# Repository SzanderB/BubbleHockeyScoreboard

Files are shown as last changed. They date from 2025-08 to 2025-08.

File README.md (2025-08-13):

# Bubble Hockey Scoreboard

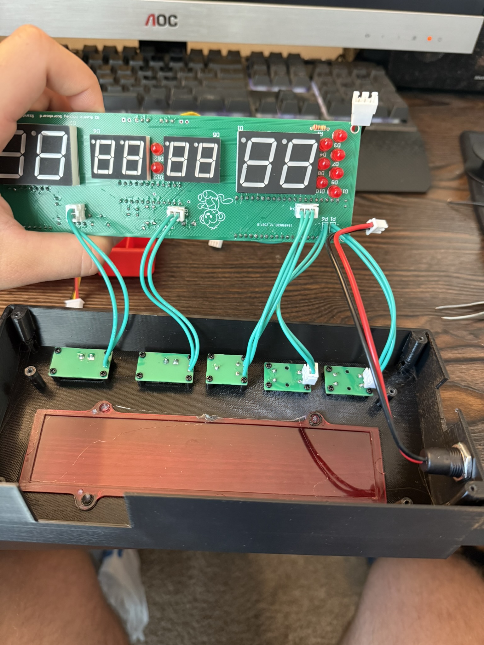
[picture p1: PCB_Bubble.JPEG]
Bubble Hockey Scoreboard
  
[🎥 Video Demo](https://youtu.be/nwzQTY0Y3hk)

## Overview
A fully custom scoreboard for a bubble hockey table (or any goal-based game), built from schematic design to a finished 3D-printed enclosure. Tracks goals automatically, plays audio cues, and supports multiple game modes.  
Includes two versions:
- **V1** – PCB-only prototype for a class project
- **V2** – Redesigned, fully integrated product with mechanical housing

## Features
- Automatic goal detection via beam-break sensors
- Multiple game modes (play to score limit or timed matches)
- Ambient lighting with NeoPixel LEDs
- Audio effects via DFPlayer Mini MP3 player
- Modular design with Molex connectors for easy assembly/disassembly

## Tech Stack / Components
- **MCU:** Raspberry Pi Pico 2
- **Display:** MAX7219-driven 7-segment LEDs
- **Lighting:** NeoPixel LEDs (FastLED library)
- **Audio:** DFPlayer Mini + external amp
- **Enclosure:** Custom 3D-printed case with mounting hardware
- **Other:** Beam-break sensors, tactile buttons, toggle switches, potentiometer

## Design Notes
- Learned to integrate mechanical constraints into PCB design
- Balanced routing efficiency with component placement for enclosure fit
- Iterated enclosure to allow access to key ports while assembled

## Future Improvements
- Better speaker and button hole tolerances in the case
- Integrate light switch state detection directly into firmware
- Correct PCB LED footprint for better fit

## Media
- [Video Demo](https://youtu.be/nwzQTY0Y3hk)

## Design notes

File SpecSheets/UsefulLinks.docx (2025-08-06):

LEDs

https://www.uxcell.com/common-cathode-pin-bit-segment-141-102-039-inch-red-led-display-digital-tube-2pcs-p-1444941.html

https://www.xlitx.com/7-segment-led-dot-matrix/5621ah.html

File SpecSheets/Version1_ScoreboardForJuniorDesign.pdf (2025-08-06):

1

Szander Brenner
4/23/2025
99974691

### EE Design 1 Technical Report Final Project “Bubble Hockey Scoreboard”

## Contents

2

## Introduction

I recently acquired a Bubble Hockey table. It is not a complex and expensive version with a button-deployable puck, but it does come with a scoreboard that tracks goals and game state. However, this scoreboard was broken. The goal of my system was to replace this scoreboard and recover the functionality from the previous version. This meant it needed to have a sensor that can automatically track goals. It needed a speaker that could play sounds with the goals and with the game ending. In addition, it needed some indicator of current goals and game time.
Ideally, this system would be small enough to be mounted to the bubble hockey arena and be powered from a 9V battery. In completion, all these goals were met, but there is room for improvement in the next revision.

## Methods

### Requirements

In this section, I will discuss why I chose the components I did to fulfill the requirements. For this project, we needed an analog input, analog output, digital input, digital output, an analog signal amplified to a speaker, system status displayed on an LCD, and some sort of power regulation.

Since I was designing a scoreboard, I knew that the speaker output would come from a goal score and game ending like in the actual sport. The LCD would display all the game information like game time and score. Furthermore, the sensor most used for detecting if a goal was scored is the beam break sensor. This is the same device used in garage doors to detect if something is blocking the garage door path. This is a digital input as described in its datasheet (Digikey). This takes care of the digital input, analog output and LCD requirements.

The only things left to decide are digital output, and analog input. I originally wanted to have seven segment displays display the number for score and time, but I realized that with that configuration I couldn’t just do GPIO mapping, I would need a special seven segment driver chip to control 8 seven segments. Instead, for simplicity I just used five LEDs for each side to track goals if we are playing a game to either 3 or 5 goals. For the analog input, I decided to use a potentiometer to be a ‘state selector’. You can scroll through the different game options depending on the voltage on the output. Lastly, I went with the switching regulator as my power regulator. While it does take up significantly more space on the PCB, its efficiency was better. This was found in a previous lab. Since I wanted this to be battery powered, I could sacrifice that space for longer lasting batteries. With all my components selected, I can begin researching more into the components and designing the system.

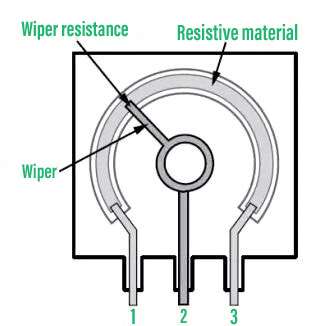
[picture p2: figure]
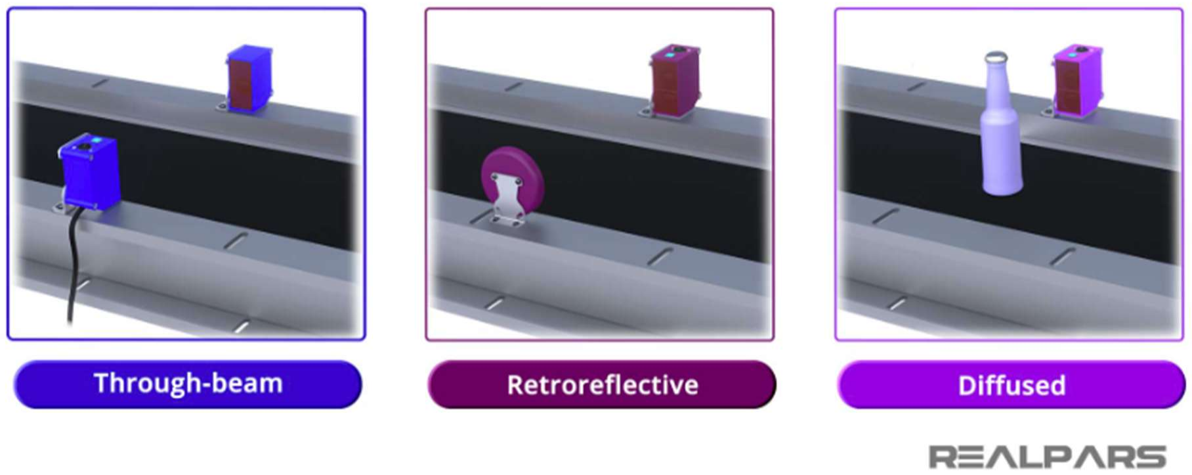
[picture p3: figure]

3

### Analog Input – Potentiometer

A typical Trimpot potentiometer has a pinout like the one seen to the right (GeeksforGeeks, 2021). There are two fixed ends that connect to either side of the total resistive material. The middle wiper pin can be spun using a dial to connect to any part of the potentiometer. From Ohm’s Law we know that V = I*R. Resistance (R) is equal to pL/A where p is rho for resistivity of the element and A is the cross-sectional area of the wire. In a potentiometer or rheostat, the cross-sectional area is kept constant, and the materials resistivity is kept constant. Therefore, we can modulate the L of the material by connecting the wiper to various points in the material, effectively changing the resistance. These potentiometers are used in a wide range of applications, but most
notably audio systems for volume modulation.

### Digital Input – Beam Break Sensor

The beam break sensor is the real neat part of this project. The concept is in a lot of common places, most notably garage doors (RealPars.). There are also multiple different styles of photoelectric sensors. The main three are the through-beam (beam break), retroreflective, and diffused. The image below shows their setups.

They all operate on the same principle. The differences are that the through-beam requires a separate emitter and reciever to send and catch the light, the retroreflective beam has a mirror to reflect it, so the emitter and reciever are the same element, and the diffused sends a beam and when some object reflects the light back, that counts as a trigger. In each of the setups, a beam of IR light is sent to a reciever. The reciever gets hit by the beam, which relies on the photoelectric effect. The IR light excites electrons in the material, generating a measurable current. In the first two configurations, the through-beam and retroreflective, the ‘normal’ state is continuous current. When the current stops, there is something in the beams path, triggering the sensor to output either a high signal or low signal

Figure 1: Potentiometer
Pinout (GeekforGeeks, 2021)

Figure 2: Types of Photoelectric Sensors(RealPars.)

4

depending on the manufacturer specifications. The diffused works opposite to this. There is no received beam until something moves in its path and reflects the light. In my system, I am using the through beam to detect when a puck passes into the goal. The signal is sent to my microcontroller for processing.

### DAC to Audio Amplifier

DAC
The last complex aspect of this project is to create the audio output for the speaker. We will be outputting a signal to a DAC since our Pico does not have a built in DAC. The DAC will output a voltage to an audio amplifier for a signal that can drive a speaker. For a quick background, DACs take in digital value and produce an analog signal out, typically 0-5V. Our DAC, the LTC1661, takes 2.7V-5.5V VCC, which means that it can provide output voltage from 0-5V (Analog Devices). Our chip is programmed through SPI. It has no MISO pin, meaning no data can be read from the device. However, there are only 3 operations we have for each channel. Load, Wake, and Load and Wake. Our DAC has a 10-bit resolution, meaning that we have 1024 steps from 0V to our Vref.

How do DACs work?
There are a few different types of DACs. There are Resistor String DACs, Binary Weighted, R-2R Ladder, and Sigma-Delta DACs. Each has some benefits and tradeoffs. Resistor Strings are slow and require lots of resistors for higher resolution. Binary Weighted uses resistors with values weighted by powers of 2, but they require more precise resistor values. R-2R are very common and use only two resistor values (R and 2R) in a ladder configuration, reducing complexity while maintaining precision. Sigma-Delta DACs are more expensive and higher quality, usually found in audio systems (OpenAI, 03/2025).
Our DAC is a resistor string architecture. This allows rail-to-rail output voltages and are typically found in low power, small scale DACs like our LTC1661. They only draw around 60 uA per DAC (there are two on the chip).
Where are DACs used?
DACs are used all around, but most widely used in audio systems. Our songs and software are all ones and zeros, but if we wanted to create a signal that we can hear, we need to transfer it into an analog signal. This is where DACs are used.
Not only that, but last week we saw that DACs are used in ADCs too. Using successive approximation register ADCs, they use a DAC to output a voltage to compare to. This makes them very important to applications requiring ADCs, which are about any monitoring system or program with a sensor.
Amplifiers
Op-amps were developed in the 1930s-1950s to conduct analog computing for mathematical expressions like adding, subtracting, and multiplying (OpenAI, 2025). They are also used for easy amplification of analog signals for communications and measurement systems. Due to their high gain and overall versatility, they have many applications. To customize them to meet system requirements, the feedback is set by connecting the output to one of the input terminals with a direct connection or through other electronic components like capacitors and resistors.

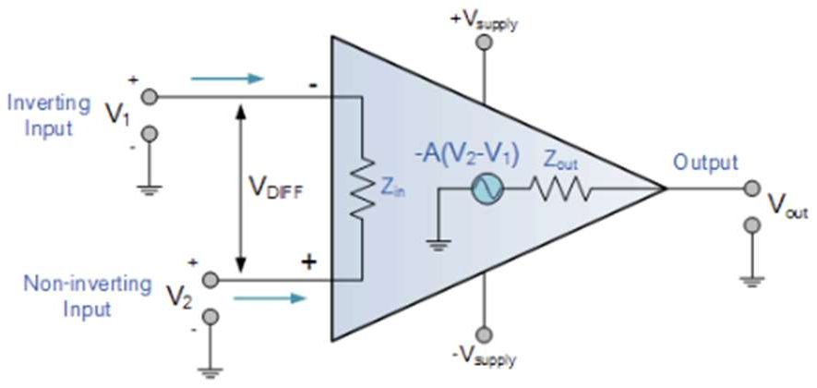
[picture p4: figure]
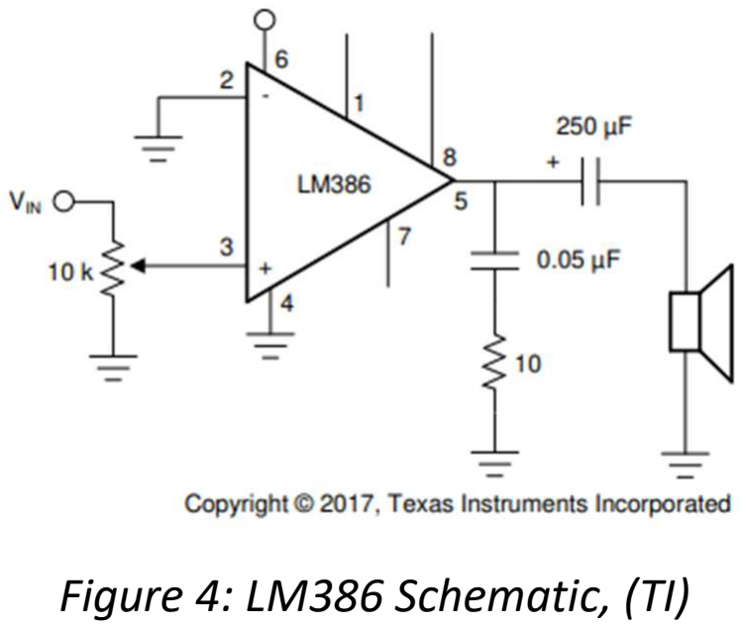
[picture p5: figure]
Figure 4: LM386 Schematic, (TI)

5

Their layout typically consists of 3 signal terminals and two voltage (for power) terminals. A diagram is shown on the right. The two inputs are typically labelled inverting and non-inverting input. This is because typically if your input signal is connected to the inverting input, the output will invert the level of voltage. For example, 5V in goes -5V out depending on the input power rails. Both
inputs are very high impedance and therefore draw
very little current from the input. The output can
both source and sink current, meaning that they can provide current/voltage and also take excess to ground (Storr, 2024). However, for most op-amps, this is on the order of milliamps. This introduces the need for differentiation between general op amps and audio amplifiers which are designed to drive low impedance loads like speakers and provide high current.

There are many ways to choose an op-amp for the circuit you are designing. The main metrics to focus on are Rail-to-Rail, Gain Bandwidth product, slew rate, operating voltage, max operating temperature, operating supply current, common mode rejection ratio, input referred noise, and mounting style (ECE3923C Design 1). Rail-to rail specifies that the output can (or cannot) swing to and from the voltages you provide for power. This is helpful when you know what voltage output you need, and whether you need full range or not. Gain bandwidth product is important for high frequency circuits. This selects the range of frequencies that the op amp can handle without breakdown. Slew rate is the speed at which output can change. Operating voltage is always important because it sets what power supply you need. Max operating temperature is important if you are in harsh conditions. Operating supply current specifies how much current the op amp requires, so is important in low-power settings. Common-mode rejection is how much noise common to both input signals is rejected. Input referred noise is how much noise is added to the input signal through the op amp. Lastly, mounting style affects the manufacturability of your product.

For my project, I needed to use an audio amplifier
because regular op amps do not drive enough current for low
ohm loads like a speaker (AllAboutCircuits, 2019). The LM386 is the ideal choice for our project because it is readily available, supports wide voltage range for input, and has good documentation behind it (TI). The right shows the general schematic for a constant gain of 20 with a volume control (TI). This will effectively drive an 8 ohm speaker needed for the project.

Figure 3: Op amp general image, (Storr, 2024)

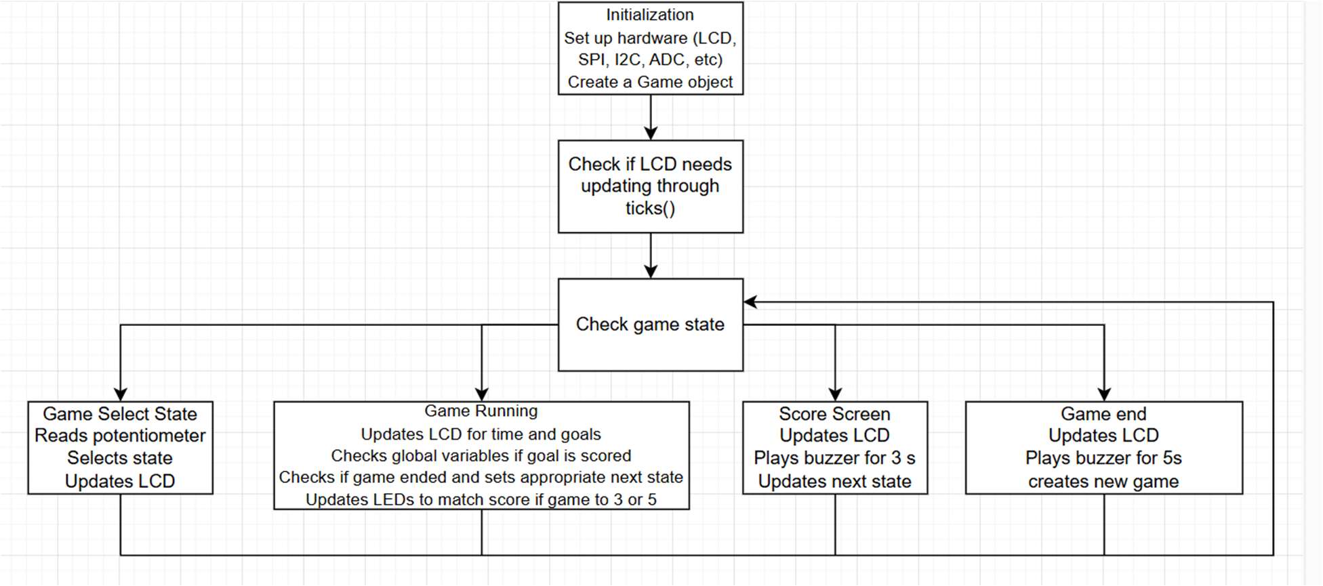
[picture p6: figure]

6

### Software Block Diagram

Figure 5: Software Code Diagram The code above shows the general flow through the program. It does not explain the nuances of the code, however. I will explain how it works in this section. I split my code into 4 main files, main, game_logic, hardware, and constants. The main file organizes all the files and acts as the controller. If you are familiar with controller and datapath configuration, the game_logic is the datapath. I created a Game object that tracks all the relevant states such as current time, goals, state, etc. The main file checks this game object’s current state and then calls the function corresponding to it in the game_logic file. This allows for better segmentation of code and increased readability. The hardware file is responsible for setting up all the hardware like the SPI and I2C channels. This way, my main can be more readable when I call init_DAC() and the other functions. This file also handles the interrupts. There are two main ones, button press and goal score. The interrupts both update a dictionary of flags which can be read from any file. The constants is a static file that just holds important values like pin values.

The game_logic is the brunt of the program with 180 lines of code. It is split into 4 sections corresponding to the 4 states a game could be in: Select, running, goal scored, and game over. The select state reads an ACD and based on its value, will output one of 5 options for gameplay. Once a button is pressed, it will set the next state to running and make sure the game is configured based on the selection.

In the running state, this will check whether a goal has been scored and needs to be updated. If so, it will set the next state to the goal scored state, update the counter and corresponding LED if we are playing a game to a set score, and finally check if the game has won. If it’s ended, it’ll branch to the game ending state instead.

In the goal scored state, it changes the LCD to say “GOAL!” and plays the buzzer for 3 seconds. It changes the next state to be the running state.

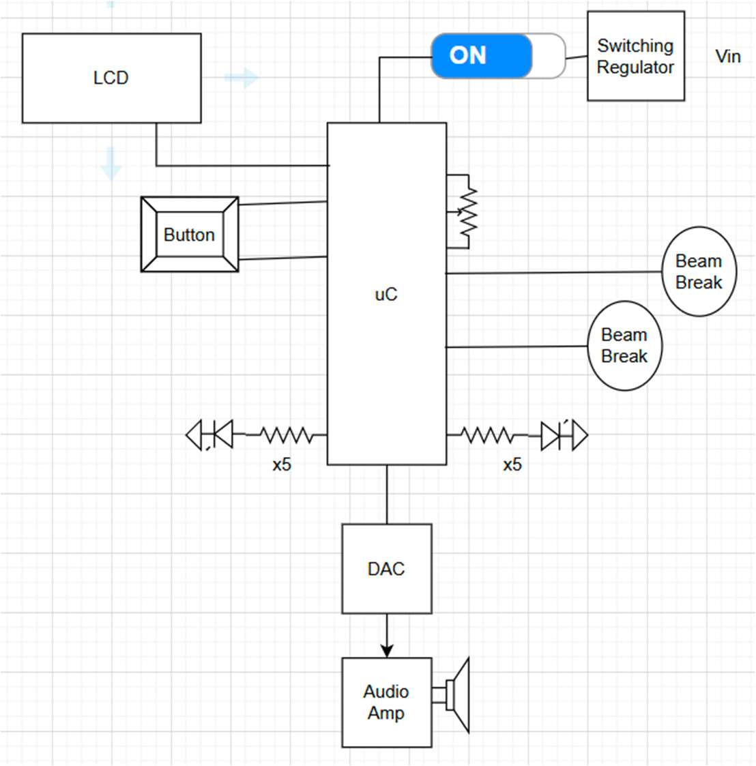
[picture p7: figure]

7

In the game over state, it assesses who won, outputs to the LCD correctly, plays the buzzer for 5 seconds, resets the LEDs and overall game state, and sets the next state equal to the select state. This completes the code loop and ensures that a new game can be played right after the end of the previous one. A decent amount of the code and structure was generated by ChatGPT, and I am referencing them here (ChatGPT, 2025).

### Hardware Block Diagram

To the right shows the basic implementation of the
circuit. The main components include a power regulation circuit in the form of a switching regulator, an on/off switch for the device, an LCD to display current state of the device, a potentiometer to gather analog data to select the proper state of the device, a button to select the state and move onto the running of the game, 10 total LEDs to display current goals, two beam break sensors to detect when goals are scored, and DAC, audio amplifier and a speaker to output sound from the game. This captures all the requirements of the system.

Figure 6: Hardware Block Diagram

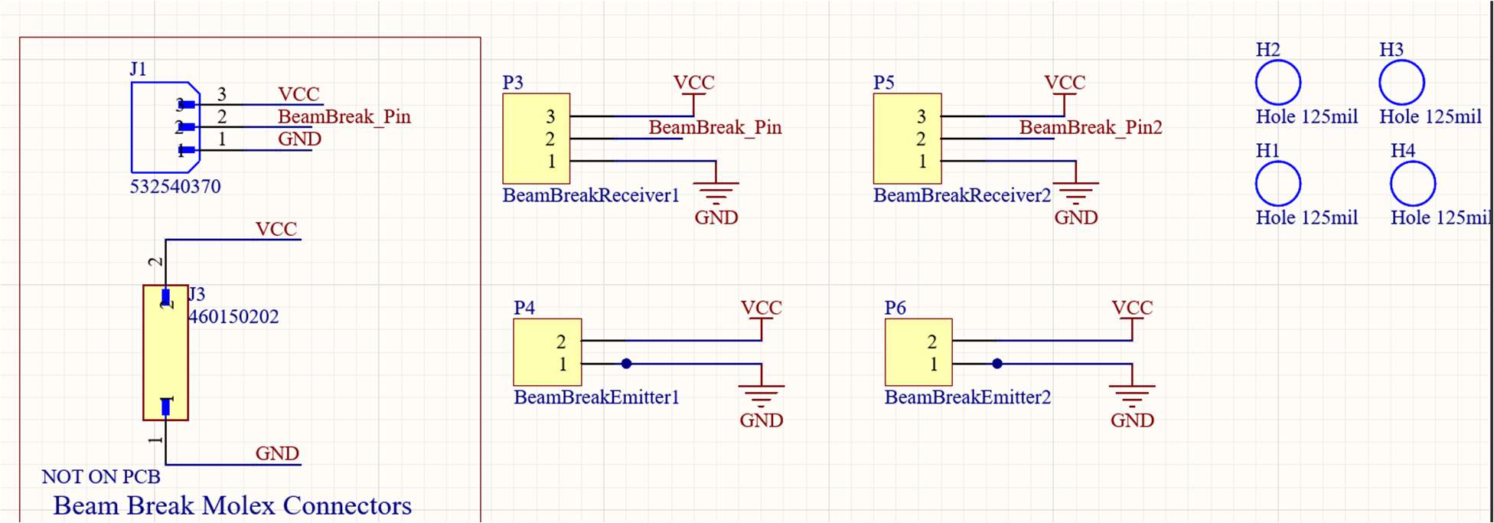
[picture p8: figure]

8

### Altium Schematic

Figure 7: Header pins for Beam Break sensors. Above shows part of the Altium Schematic that shows the through holes for mounting (on the right) as well as the headers that the beam break sensors take. The emitters just require power, and the receivers have 1 more pin for the signal. I wanted to eventually plan to replace the header pins with Molex so that it is less likely that wires fall out, so that is shown on the left.

This part of the schematic to the left corresponds to the LCD. On the actual PCB, I just need a 4-pin header as shown on the bottom right. The left box is the actual LCD with its 16 pins out, and they connect to the I2C LCD backpack. This allows us to use I2C to control the LCD instead of the 16-pin protocol it normally has.

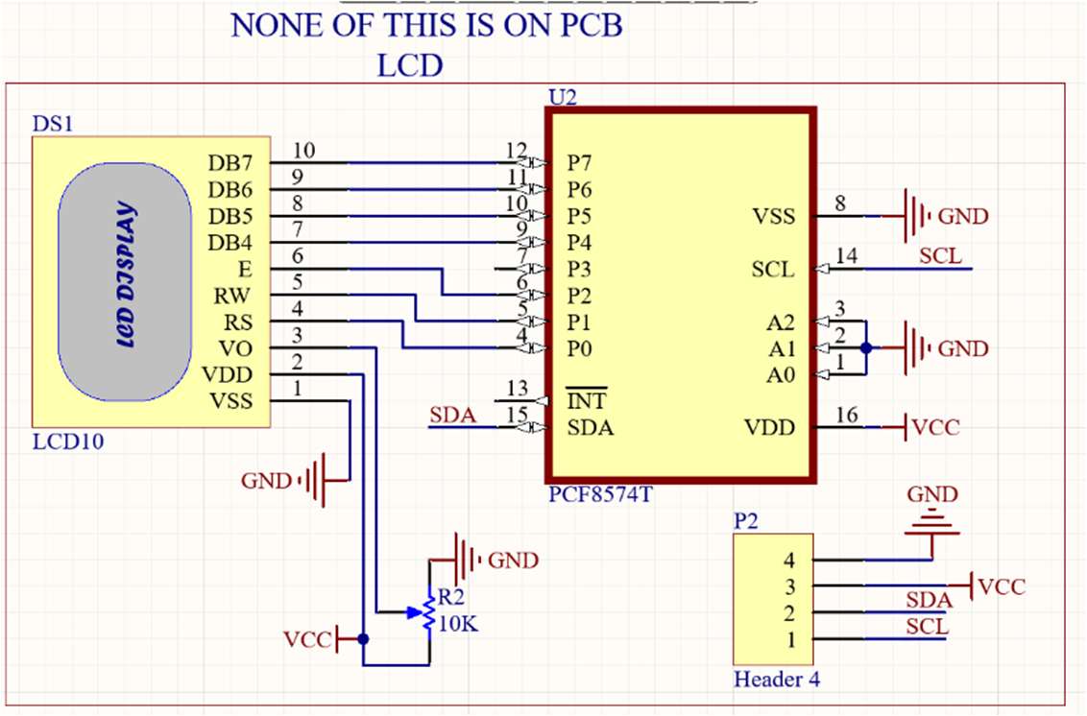
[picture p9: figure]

Figure 8: LCD Schematic

9

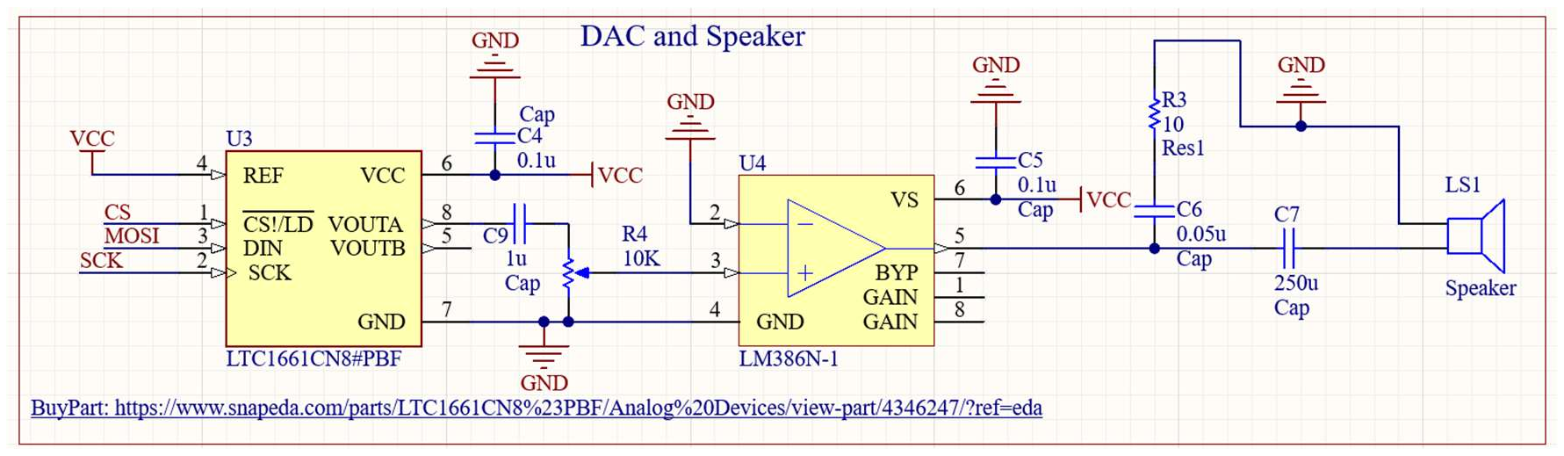
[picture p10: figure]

Figure 9: Speaker System Schematic This is the schematic for the speaker system. The microcontroller sends out a signal through SPI to an external DAC. This DAC converts the message to an analog voltage, sends that to the audio amplifier which can drive low impedance loads like a speaker.

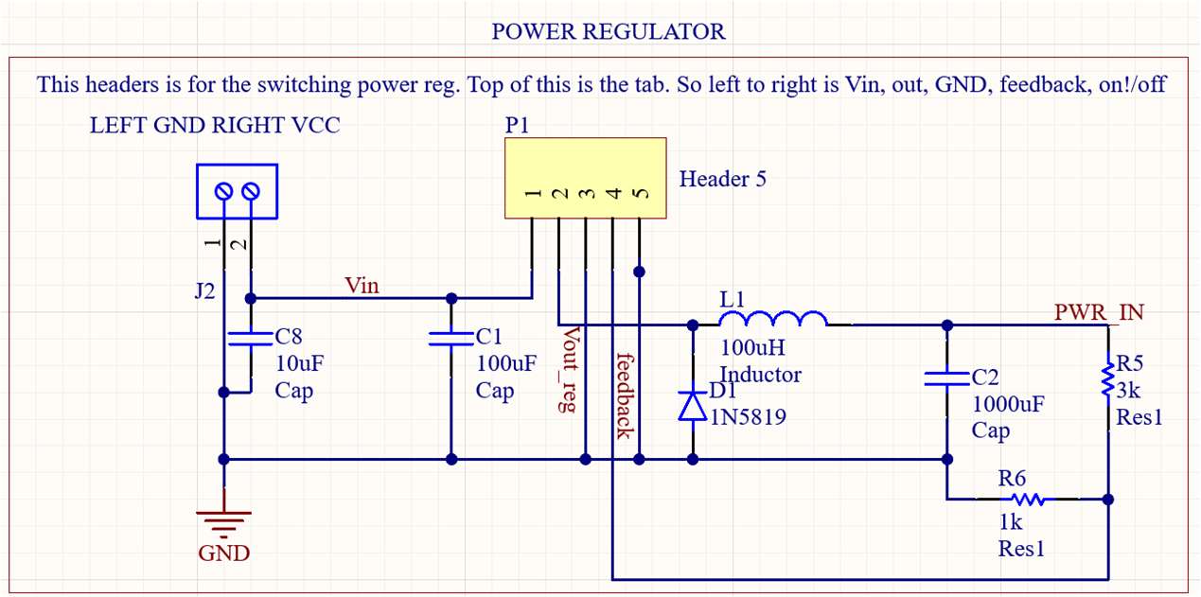
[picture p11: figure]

Figure 10: Power Regulation Schematic

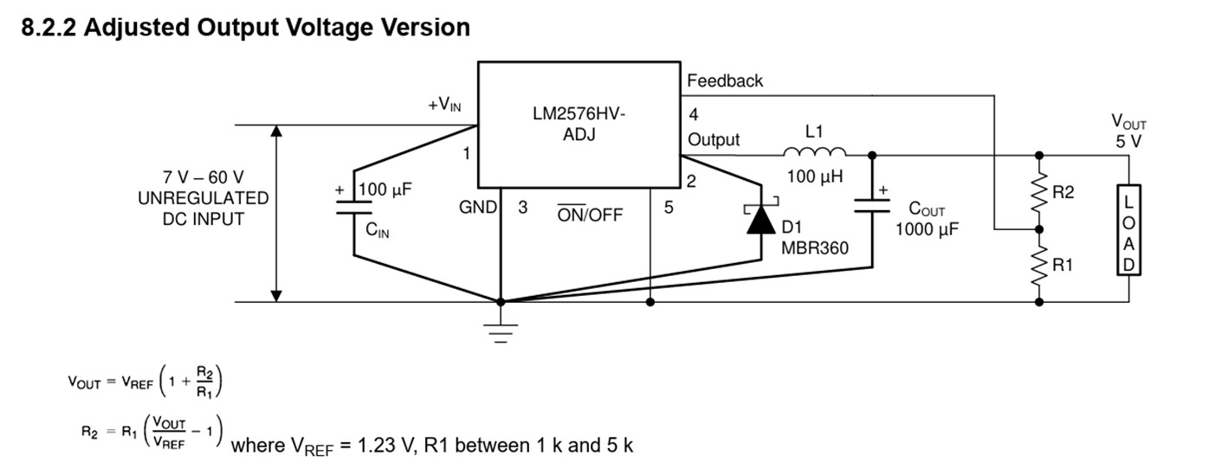
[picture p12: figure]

Figure 11: TI Datasheet for LM2576 Switching Regulator for adjusted output voltage (TI) The switching regulator schematic can be found in its data sheet and mirrors this (TI). The R2 and R1 were chosen to get a 5V output and a 10uF capacitor was added to the input of the power for added signal smoothing. The rest is as the datasheet expects.

10

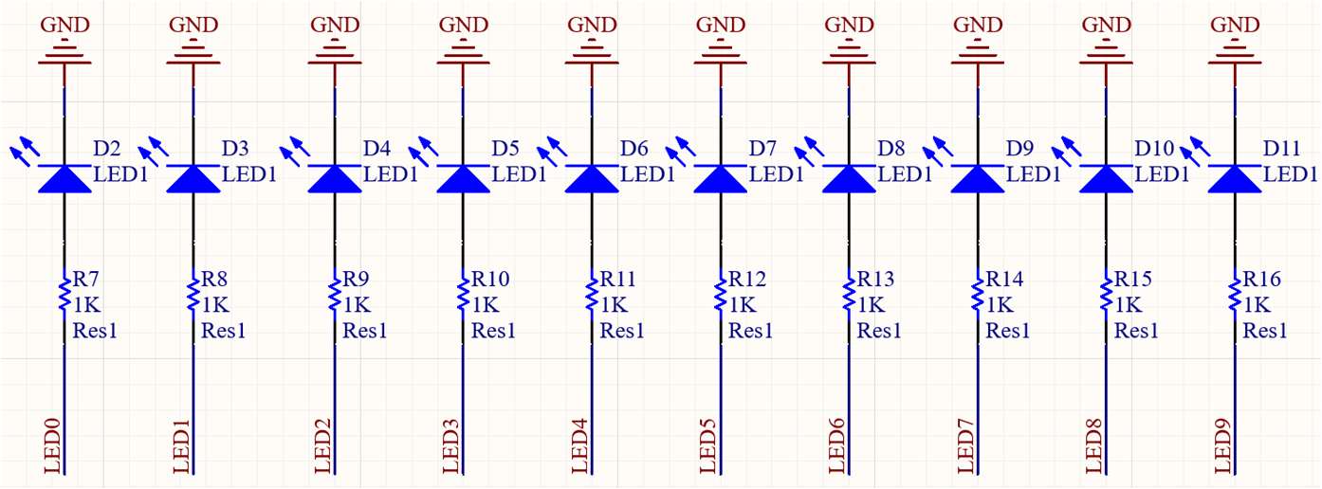
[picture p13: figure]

Figure 12: Simple LED Array Above shows the basic 10 LED array (5 for each side) that represents the current goal tally. They are each connected to their own GPIO pin.

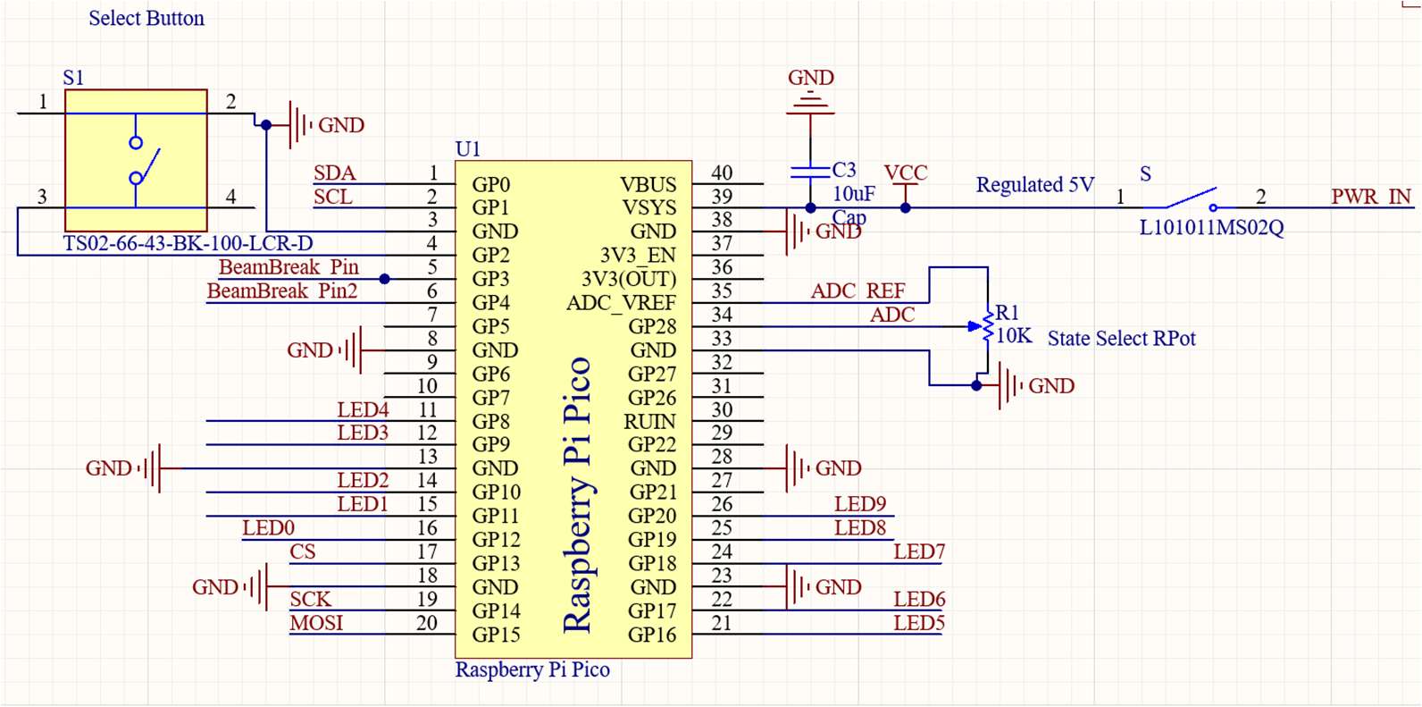
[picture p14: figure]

Figure 13: Microcontroller Pin Connections as well as the button, on/off switch, and state select potentiometer.
Above shows the remaining components in the schematic. The button connects to one GPIO pin and to ground. The On/Off switch connects the power regulator circuit to the rest of the board. The potentiometer connects to the ADC reference, ADC input, and GND. All the rest of the pins are labeled with net labels. The bottom has the SPI module, and the top has the LCD.

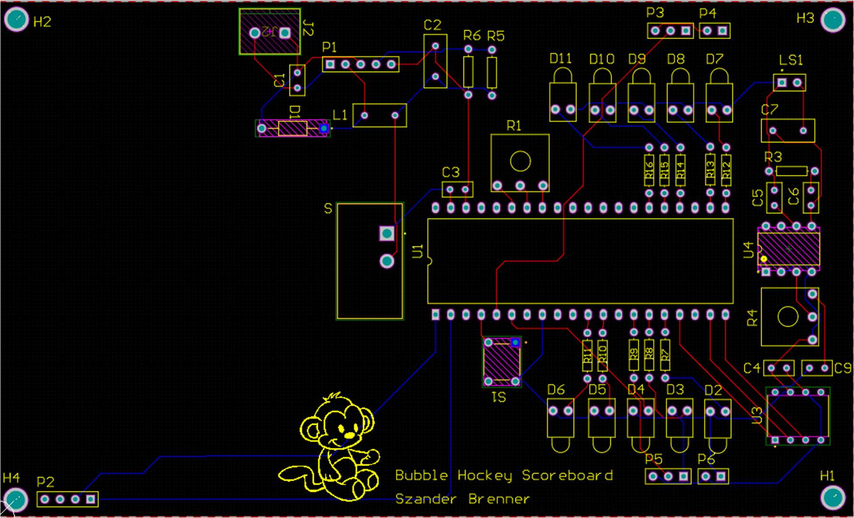
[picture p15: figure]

11

### Altium PCB

Figure 14: Altium PCB without Polygon Pours The above image shows the layout of the board. This does not show the polygon pours. The top layer has a pour for VCC, and the bottom layer contains the ground. This allows for better signal and heat conduction throughout the entire board. If we relied on just traces, the parasitics of the trace could impact the function. The LCD sits on the left side of the board. There will be a 4-pin right angle header that allows the LCD to slide in and cover the entire top region. The power regulator sits in a 5-pin header P1 at the top. The power comes in from a screw terminal J2. Before the power gets to the microcontroller, it passes through a 4A rated switch to control if the circuit is on or off. On all the ICs and the microcontroller, notice that there is a bypass capacitor as close to the pins as possible. This smooths the power input as much as possible and means there is less interference from parasitics. The LEDs are arranged equally on both sides of the board to symbolize the two team’s scores. The speaker system takes up the entire bottom of the board (right side) and eventually connects to a 2-pin header that the speaker can plug into. My main concern for this board was fitting everything in as small of an area as possible to reduce printing costs. In the end, my board was around 3 inches by 5.5 inches. I tried separating the board into two halves for the two teams to make the mechanical installation easier.

12

### Bill of Materials

The total cost of the project’s materials is around $52. The following shows the distribution.

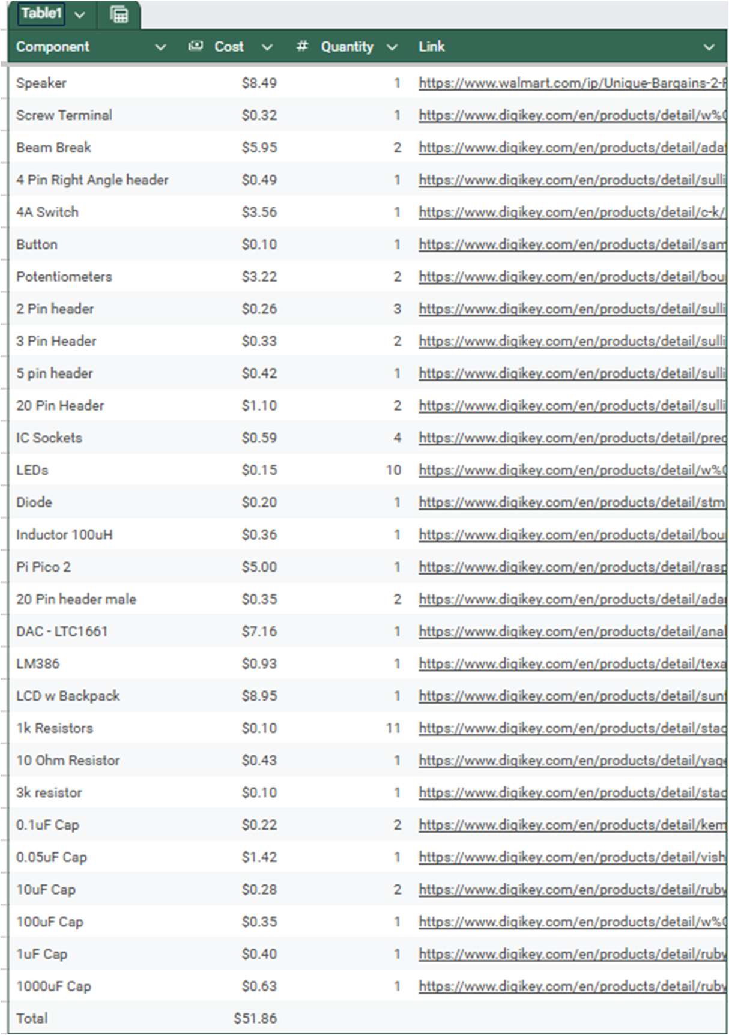
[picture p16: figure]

Figure 15: Bill of Materials with links. Google Drive Link As seen, this does not include the cost of the PCB. Depending on the shipping, it can range from $40-$100 additional cost. This price compared to commercially available scoreboards is not that impressive. The original scoreboard for the game costs $140 at Game Room Guys (Game Room Guys). My scoreboard unfortunately does not include any mechanical parts to protect the circuit or make it look more like a scoreboard. However, mine does use an LCD which is more expensive than the seven segment displays they have. Overall, if your main goal is to get the bubble hockey scoreboard working, it may be more cost and time effective to purchase it directly.

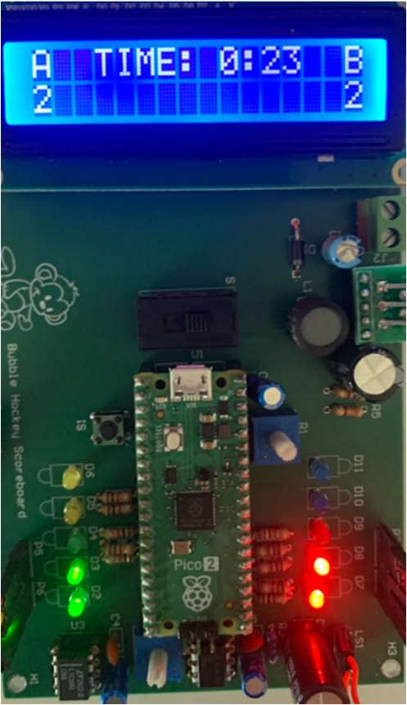
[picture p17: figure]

13

## Results

### LCD Output

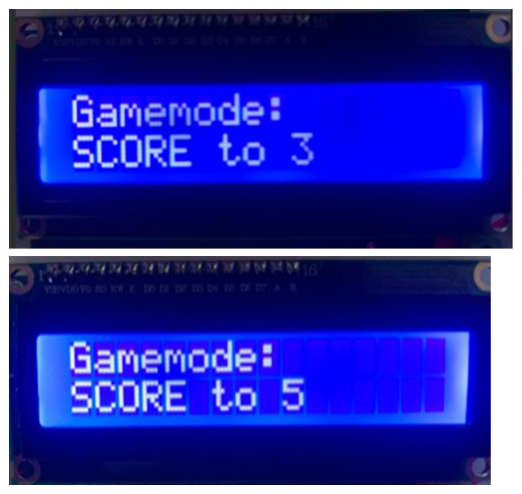
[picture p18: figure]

The above images are from the SELECT screen state. These are all toggled through using the potentiometer next to the Pico. The images on
the right show example output when the game
is running. If it is a game to a set time, the top
shows the remaining time, and the score is on the left and right. For a game with a set score, then the time shows how long you have been playing, and the goals also reflect on the LEDs on the PCB.

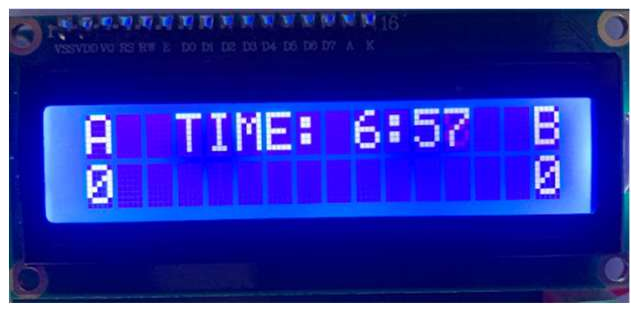
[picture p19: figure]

When someone scores, the left screen is shown for three seconds. After someone
wins, the right screen is shown for 5 seconds, then is changed back to the original state. After the game is won, the LEDs are reset back to off, and a new game can be run.

Figure 16: Select Screen Outputs

Figure 17: Game Running
Output

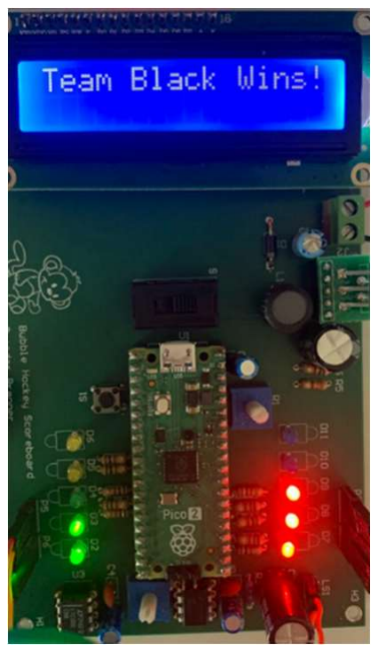
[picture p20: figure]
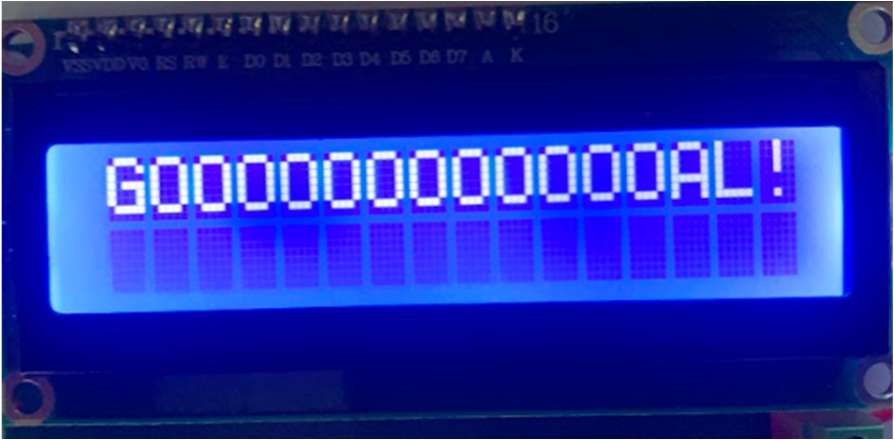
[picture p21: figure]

Figure 18: Game
Ending and Score
Screens

14

### PCB

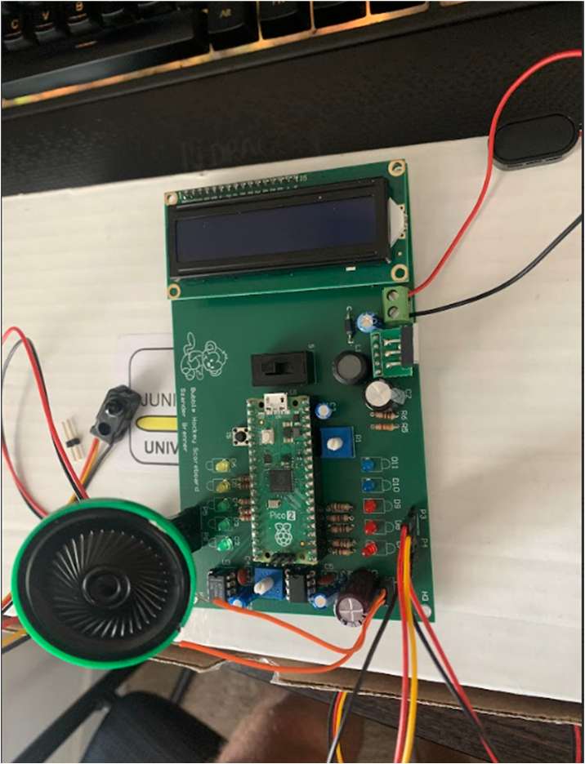
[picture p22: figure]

Figure 19: Completed PCB with Speaker and Externals The above image shows the completed PCB. As you can see, the LCD takes up the top space of the PCB just above the power input. The beam break sensors plug into either side of the PCB corresponding to the LEDs and side they control. The On/Off switch is right above the Pico, but it unfortunately blocks the USB port. The Linear Regulator is in a separate PCB with a 5-pin header attached to it, so it plugs into the top 5 pin header.

### Analog Output

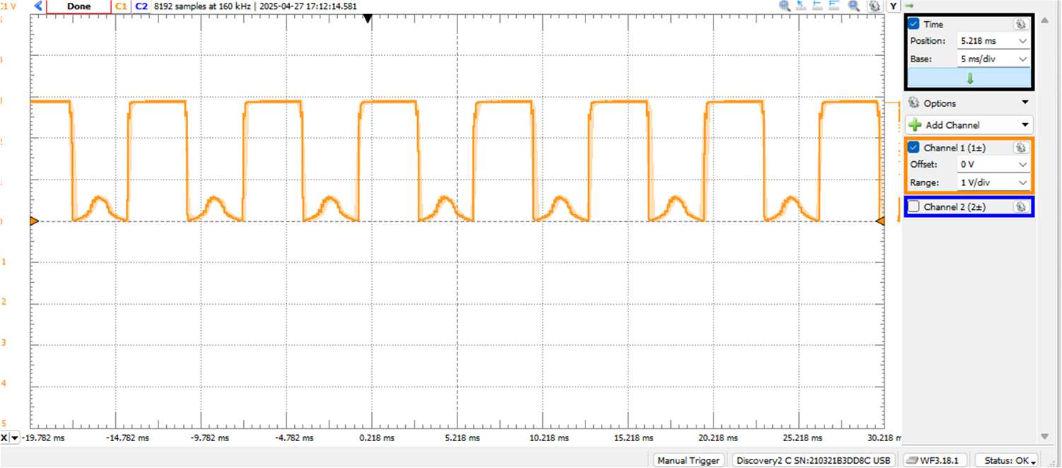
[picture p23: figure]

Figure 20: Output to Speaker from Audio Amplifier The above image is the output to the speaker from the Audio Amplifier. As you can see, it is a square wave and not a sinusoid. It is in the correct frequency, but the issue was that my output from the DAC was in reference to 5V. Therefore, I was outputting a 5V sine wave, then the audio amplifier was amplifying it by 20. This immediately hits the rails, making my sine wave square. It still sounds like a buzzer, but in future renditions, the DAC should take the future amplification into account.

15

## Discussion/Conclusion

Through the process of design to fabrication, there were many points in which I want to improve my device. However, I believe that the overall functionality is quite good. The goals and game are tracked efficiently, the LCD output is very clear and doesn’t have much flashing from rewriting constantly.

For starters, I want to take into consideration the mechanical aspects of my PCB more in the next iteration. The scoreboard will be enveloped in some sort of box to hide the electronics, and having a large rectangle makes it more difficult to make the scoreboard aesthetically pleasing. Furthermore, I like how the LCD takes up the top of the PCB and sits flush, however it wastes lots of space that I am paying for during manufacturing. Instead, I think the screen can be connected with wires to the PCB and will be mounted to the outside of the box. The same applies to the speaker and battery pack, though they are already like that now. Overall, I’d shrink my PCB and fit more into a smaller space because I want the scoreboard to be enclosed in another box.

Furthermore, as discussed in the previous page, my audio output was not as intended. I forgot to factor in the automatic 20x amplification from the LM386. Therefore, my DAC needed to output only 0-~180mV. However, outputting the audio is very CPU intensive for high resolutions. If I want to eventually output voice which needs high levels of resolution, I will need to switch to an external solution such as a dedicated memory for the sounds that can output to the DAC and LM386. The speaker will also be placed in an enclosure to boost its sound quality.

A blatant fix is to move the switch away from the USB port of the Pico. I did not realize how tall it was, and it completely blocks the Pico. That means any code changes require removing the Pico, which can be very annoying to deal with.

Even with these changes, I believe that my project was very educational and complete. This process gave me the confidence to expand on my project in future renditions. Learning how to create the Gerber files to send to a manufacturer empowers me to continue developing and making physical products.

16

## References

Abdulwahab.hajar. (2019, December 26). Opamp vs audio amplifier??. All About Circuits. https://forum.allaboutcircuits.com/threads/opamp-vs-audio-amplifier.135094/

Digikey. (n.d.). Beam Break Sensor 2168. Digikey Components. https://mm.digikey.com/Volume0/opasdata/d220001/medias/docus/44/2168_Web.pdf

Game Room Guys. (n.d.). Shelti electronic scoring unit. Retrieved April 30, 2025, from https://www.gameroomguys.com/Shelti-Electronic-Scoring-Unit_2

GeeksforGeeks. (2021, September 27). Potentiometer - definition, working principle, types. https://www.geeksforgeeks.org/potentiometer-definition-working-principle-types/

LM2576. LM2576 data sheet, product information and support | TI.com. (n.d.).
https://www.ti.com/product/LM2576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

OpenAI. (2025, April 27). Response from ChatGPT [Large language model]. OpenAI. https://chat.openai.com/

RealPars. (n.d.). Photoelectric sensor explained (with practical examples) - realpars. RSS. https://www.realpars.com/blog/photoelectric-sensor#:~:text=For%20the%20Through%2DBeam%20sensor,the%20sensor%20will%20turn%20 off.

Storr, W. (2024, August 9). Operational amplifier basics - op-amp tutorial. Basic Electronics Tutorials. https://www.electronics-tutorials.ws/opamp/opamp_1.html

Ti. (n.d.). https://www.ti.com/lit/ds/symlink/lm386.pdf

17

## Appendix

1. <main.py>
2. # library imports…

### 3. import hardware 4. import game_logic 5. import time 6. import constants

7.
8. #lcd_timer = Timer(3)
9. #lcd_timer.init(freq = 0.5, mode = Timer.PERIODIC, callback=lcd_update) 10.

### 11. def main():

12. # Init hardware

### 13. player_a_leds, player_b_leds = hardware.init_LEDs() 14. start, beam_a, beam_b = hardware.init_sensors() 15. spi, cs = hardware.init_DAC() 16. lcd = hardware.init_LCD() 17. adc = hardware.init_adc()

18.
19. # Init game state

### 20. game = game_logic.GameState()

21.

### 22. lcd_update_time = time.ticks_ms() 23. lcd_update = {'update' : True} 24. while True:

25. #get flags

### 26. flags ={

27. 'f_start' : hardware.button_pressed,
28. 'f_goal_a' : hardware.goal_a_flag,
29. 'f_goal_b' : hardware.goal_b_flag
30. }
31.
32.

### 33. if(time.ticks_ms()-lcd_update_time > 500): 34. lcd_update['update'] = True 35. lcd_update_time = time.ticks_ms()

36.

### 37. if game.state == 'SELECT': 38. game_logic.handle_select(game, adc, flags, lcd, lcd_update) 39. elif game.state == 'GAME_RUNNING':

40. game_logic.handle_game_running(game, player_a_leds, player_b_leds, flags, lcd, lcd_update)
41.

### 42. elif game.state == 'SCORE_SCREEN': 43. game_logic.handle_score_screen(game, cs, spi, lcd, lcd_update)

44.

### 45. elif game.state == 'GAME_END': 46. game_logic.handle_game_end(game, cs, spi, lcd, lcd_update)

47. # make a new game

### 48. game = game_logic.GameState()

49.
50. | hardware.clear_flags() | # clear flags on each loop
51.

### 52. time.sleep_ms(10) # loop timing

53.

### 54. main()

55. </main.py>
56. <game_logic.py>
57. # game_logic.py is like the datapath and handles all the logic for each state

### 58. import time 59. from machine import Pin, SPI, I2C, ADC, Timer

18

### 60. import constants

61.

### 62. GAME_OPTIONS = [

63. {'mode': 'SCORE', 'target_score': 3},
64. {'mode': 'SCORE', 'target_score': 5},
65. {'mode': 'TIMER', 'target_time': 180},
66. {'mode': 'TIMER', 'target_time': 300},
67. {'mode': 'TIMER', 'target_time': 420},
68. ]
69.

### 70. sine_timer = Timer() 71. table_index = 0

72.

### 73. class GameState: 74. def __init__(self): 75. self.state = 'SELECT'

76. | self.mode = 'SCORE' | # or timer

### 77. self.target_score = 5 78. self.score_a = 0 79. self.score_b = 0

80. | self.target_time = 300 | # in seconds, so 5 mins

### 81. self.goal_time = 0 82. self.start_time = time.ticks_ms()

83.

### 84. def handle_select(game, adc, flags, lcd, lcd_update):

85.
86.
87. # read potentiometer for char and map to 0-4 for state select

### 88. val = (adc.read_u16() * len(GAME_OPTIONS)) // constants.MAXU16

89.

### 90. selected = GAME_OPTIONS[val] 91. game.mode = selected['mode']

92. | game.target_score = selected.get('target_score', 0) | # gets target score if there is one
93. | game.target_time = selected.get('target_time', 0) | # same here
94. # wait for button press → move to 'GAME_RUNNING'
95.
96. #update lcd if needed
97.

### 98. if(lcd_update['update']): 99. lcd_update['update'] = False

100. lcd.clear()
101. lcd.putstr("Gamemode: ")
102. lcd.move_to(0,1)
103. if game.target_score != 0:
104. lcd.putstr(f"{game.mode} to {game.target_score}")
105. else:
106. lcd.putstr(f"{game.mode} for {game.target_time}s")
107. if(flags['f_start']):
108. game.state='GAME_RUNNING'
109. lcd_update['update'] = True
110. game.start_time = time.ticks_ms()
111. pass
112.
113. def handle_game_running(game, leds_a, leds_b, flags, lcd, lcd_update):
114. # update lcd if needed
115. if(lcd_update['update']):
116. lcd_update['update'] = False
117. lcd.clear()
118. #place time
119. lcd.move_to(0, 0)
120. lcd.putstr("A TIME: " + get_game_time(game) + " B")
121. #place scores
122. lcd.move_to(0, 1)
123. lcd.putstr("{}".format(game.score_a))
124. lcd.move_to(15, 1)

19

125. lcd.putstr("{}".format(game.score_b)) 126.
127. # check beam break → update score
128. # if goal: change to 'SCORE_SCREEN'
129. if(flags['f_goal_a']):
130. game.score_a += 1
131. game.state = "SCORE_SCREEN"
132. if(flags['f_goal_b']):
133. game.score_b += 1
134. game.state = "SCORE_SCREEN"
135. # update LED arrays
136. for i in range(game.score_a):
137. leds_a[i].value(1)
138. for i in range(game.score_b):
139. leds_b[i].value(1)
140.
141. # if timer or score limit: change to 'GAME_END'
142. if game.mode == 'SCORE':
143. if game.score_a >= game.target_score or game.score_b >= game.target_score:
144. game.state = 'GAME_END'
145.
146. elif game.mode == 'TIMER':
147. elapsed = time.ticks_diff(time.ticks_ms(), game.start_time) // 1000
148. if elapsed >= game.target_time:
149. game.state = 'GAME_END'
150. pass
151.
152. def handle_score_screen(game, cs, spi, lcd, lcd_update):
153. # wait 3 seconds → return to 'GAME_RUNNING'
154. #set LCD to Score!
155. lcd.clear()
156. lcd.putstr(f"GOOOOOOOOOOOOAL!")
157.
158. # start sine_timer
159. print("Sine Started")
160. start_sine_wave(cs, spi)
161. #sit in while loop
162. start = time.ticks_ms()
163.
164. while time.ticks_diff(time.ticks_ms(), start) < 3000:
165. pass
166. print("Sine Stopped")
167. stop_sine_wave()
168. game.state = 'GAME_RUNNING'
169. lcd_update['update'] = True
170. pass
171.
172. def handle_game_end(game, cs, spi, lcd, lcd_update):
173. # wait 5 seconds → reset game → 'SELECT'
174. # set LCD to winner of game
175. lcd.clear()
176. if(game.score_a > game.score_b):
177. lcd.putstr(f"Team Red Wins!")
178. else:
179. lcd.putstr(f"Team Black Wins!")
180. # start sine_timer
181. start_sine_wave(cs, spi)
182. #sit in while loop
183. start = time.ticks_ms()
184.
185. while time.ticks_diff(time.ticks_ms(), start) < 5000:
186. pass
187.
188. stop_sine_wave()
189.

20

190. game.state = 'SELECT' # redundant since itll be reset in main but here anyways
191. lcd_update['update'] = True
192. pass
193.
194. def get_game_time(game):
195. elapsed = time.ticks_diff(time.ticks_ms(), game.start_time) // 1000 # in seconds 196.
197. if game.mode == 'TIMER':
198. remaining = max(0, game.target_time - elapsed)
199. minutes = remaining // 60
200. seconds = remaining % 60
201. return f"{minutes:01}:{seconds:02}" # e.g. "2:03"
202. else:
203. # Just show elapsed time in SCORE mode
204. minutes = elapsed // 60
205. seconds = elapsed % 60
206. return f"{minutes:01}:{seconds:02}" 207.
208.
209. # FOR TIMER STUFF
210. # SPI Send Function
211. def send_to_dac(value, cs, spi):
212. global table_index
213. cs.value(0)
214. buf=bytearray([constants.loadwakeA | (value >> 6), (value<<2) & 0xFC])
215. spi.write(buf)
216. cs.value(1)
217.
218. # Timer Interrupt to Send Sine Wave
219. def sine_wave_callback(cs, spi):
220. global table_index
221. send_to_dac(constants.sineLUT[table_index], cs, spi)
222. table_index = (table_index + 1) % len(constants.sineLUT) # Loop through sine wave table 223.
224. # Timer to generate 350 Hz sine wave
225. def start_sine_wave(cs, spi):
226. sine_timer.init(freq=constants.freq_out*len(constants.sineLUT), mode=Timer.PERIODIC, callback=sine_wave_callback(cs, spi))
227.
228. # Stop the sine wave
229. def stop_sine_wave():
230. sine_timer.deinit()
231. </game_logic.py>
232. <hardware.py>
233. from machine import Pin, SPI, I2C, ADC, Timer
234. from lcd_api import LcdApi
235. from pico_i2c_lcd import I2cLcd
236. import constants
237.
238. # These will be updated by the ISR
239. button_pressed = False
240. goal_a_flag = False
241. goal_b_flag = False
242.
243. button_timer = Timer()
244. goal_timer = Timer()
245.
246. def init_LCD():
247. #initialize your i2c module and lcd
248. i2c = I2C(0, sda=Pin(constants.SDA_pin), scl=Pin(constants.SCL_pin), freq=400000)
249. lcd = I2cLcd(i2c, constants.I2C_ADDR, constants.I2C_NUM_ROWS, constants.I2C_NUM_COLS)
250. return lcd
251.
252. def init_DAC():

21

253.
254. #set up SPI to DAC
255. sck= Pin(constants.pinSCK)
256. mosi = Pin(constants.pinTX)
257. spi = SPI(1, baudrate = 400000, polarity = 0, phase = 0, firstbit=SPI.MSB, sck=sck, mosi=mosi, miso=None)
258. cs = Pin(constants.pinCS,mode = Pin.OUT, value = 1)
259. return spi, cs
260.
261. def init_adc():
262. adc = ADC(Pin(constants.pinADC))
263. return adc
264.
265. def init_sensors():
266. # Buttons & goal sensor
267. start_button = Pin(constants.pinButton, Pin.IN, Pin.PULL_UP) # Start game
268. | beam_a = Pin(constants.pinSensorA, Pin.IN, Pin.PULL_UP) | # Goal detection
269. beam_b = Pin(constants.pinSensorB, Pin.IN, Pin.PULL_UP)
270.
271. start_button.irq(trigger=Pin.IRQ_FALLING, handler=button_handler)
272. beam_a.irq(trigger=Pin.IRQ_FALLING, handler=beam_a_handler)
273. beam_b.irq(trigger=Pin.IRQ_FALLING, handler=beam_b_handler)
274. return start_button, beam_a, beam_b
275.
276. def init_LEDs():
277. # 2 arrays of 5 leds each from constants.py
278.
279. # simple for loop to get all pins
280. player_a_leds = [Pin(pin, Pin.OUT) for pin in constants.player_a_pins]
281. player_b_leds = [Pin(pin, Pin.OUT) for pin in constants.player_b_pins] 282.
283. return player_a_leds, player_b_leds
284.
285. # ISRs that update globals to use in other files
286. def button_handler(pin):
287. button_timer.init(mode=Timer.ONE_SHOT, period=50, callback=button_debounced) 288.
289.
290. def button_debounced(t):
291. global button_pressed
292. button_pressed = True
293. button_timer.deinit() 294.
295.
296. def beam_a_handler(pin):
297. goal_timer.init(mode=Timer.ONE_SHOT, period=2, callback=beam_a_debounced) 298.
299. def beam_a_debounced(t):
300. goal_timer.deinit()
301. global goal_a_flag
302. goal_a_flag = True
303.
304. def beam_b_handler(pin):
305. goal_timer.init(mode=Timer.ONE_SHOT, period=2, callback=beam_b_debounced) 306.
307. def beam_b_debounced(t):
308. goal_timer.deinit()
309. global goal_b_flag
310. goal_b_flag = True
311.
312. def clear_flags():
313. global button_pressed, goal_a_flag, goal_b_flag
314. button_pressed = False
315. goal_a_flag = False

22

316. goal_b_flag = False
317. </hardware.py>
318. <constants.py>
319. # This file is for organization purposes
320.
321. ############### HARDWARE #######################
322. #globals
323. MAXU16 = 65535
324.
325. #I2C
326. I2C_ADDR = 0x27
327. I2C_NUM_ROWS = 2
328. I2C_NUM_COLS = 16
329. SDA_pin = 0
330. SCL_pin = 1
331.
332. #DAC
333. pinSCK = 14
334. pinCS = 13
335. pinTX = 15
336.
337. #ADC
338. pinADC = 28
339.
340. #Buttons and sensors
341. pinButton = 2
342. pinSensorA = 3
343. pinSensorB = 4
344.
345. #LEDs
346. player_a_pins = [12, 11, 10, 9, 8]
347. player_b_pins = [16, 17, 18, 19, 20]
348.
349. #Sine LUT
350. sineLUT =[0x200, 0x240, 0x27f, 0x2bc, 0x2f6, 0x32c, 0x35e, 0x38a,
351. 0x3af, 0x3ce, 0x3e6, 0x3f6, 0x3fe, 0x3fe, 0x3f6, 0x3e6,
352. 0x3ce, 0x3af, 0x38a, 0x35e, 0x32c, 0x2f6, 0x2bc, 0x27f,
353. 0x240, 0x200, 0x1bf, 0x180, 0x143, 0x109, 0xd3, 0xa1,
354. 0x75, 0x50, 0x31, 0x19, 0x9, 0x1, 0x1, 0x9,
355. 0x19, 0x31, 0x50, 0x75, 0xa1, 0xd3, 0x109, 0x143,
356. 0x180, 0x1bf]
357.
358. freq_out = 300
359. table_index = 0
360. loadwakeA = 0b10010000
361. </constants.py>

Plus the LCD codes given in previous lab.

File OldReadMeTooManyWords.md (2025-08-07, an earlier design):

# Project Title: Bubble Hockey Scoreboard
Custom manufactured Bubble Hockey (or any goal related game) Scoreboard from schematic to case!
This includes Version 1 (just PCB for a class) and Version 2 (changed design and fully built out to finished product)

Video link: https://youtu.be/nwzQTY0Y3hk

## Description
Fully custom scoreboard. It will automatically tally points when puck goes through the net, play audio corresponding to events in the game, select different game modes to play, such as to a set score or time limit. Version 2 also controls external LEDs for ambiance and light, and finally is containied in a easily modifiable and removable box that mounts to the table.

## Purpose
My bubble hockey table's scoreboard was broken, and I wanted it not to be broken. Also, I wanted to try my hand at more complex builds that required total level of thinking, from PCB design to mechanical placement. This project taught me that it's pretty easy to design a system in one lens, for example, the schematic and PCB are easy. However, when it comes to combining them with the mechanical design, things get much more challenging. Deciding where to place components to hae the smallest or most effective routing battles with how the board can be mounted or enclosed. Having to learn CAD while doing this as also a fun challenge that I tackled.

## Methods
Both versions are controlled by a Raspberry Pi Pico 2.

Version 1 uses and LCD screen for the Display, LED indicators on the board for players and goals, an external DAC to drive a speaker, some buttons and potentiometers for inputs (volume and game select), as well as beam break sensors to detect goals. I decided on these components because the class requirements included most of these, but it all changed in V2.
Version 2 uses a MAX7219 to control 8 common cathode seven segment displays with only 1 SPI port. It uses the NeoPixel LEDs and the FastLED library to control the external LEDs. Lastly, it uses a DFPlayer Mini MP3 player and amp to generate the audio. It has a start and select button, switches for power for both the scoreboard and the lights, and a potentiometer for volume.
Version 2 also has a 3D printed case. There are daughterboards for each interactable component (switches, buttons, pot) with individual mounting holes and standoffs in the case. They are connected with Molex connectors for easy assembly and disassembly (god knows I needed that).
There is a hole for mounting the barrel jack connector, as well as holes for easy access to Pico and DFPlayer mini's mp3 slot. This adds to it being able to be worked on while being fully built.

## Issues
This project isn't perfect. For one, the 3D model could be better. The speaker hole didn't really fit my speaker, and so I had to cut and shave away extra filament. The button holes didn't quite fit and had to be widened as well. On the code side, most everything works as desired. If I had to redo it again, I'd connect the switch for the lights directly to a GPIO pin so it can detect rising/high state, so I can automatically know to turn on the lights. Instead, you have to switch them on and click the select button. Overall though, it works as intended. It is mounted and fully usable, easily powered and operated. One part of the PCB also could change. I had the wrong footprint for the large LEDs, but just bent the pins to get them to fit.

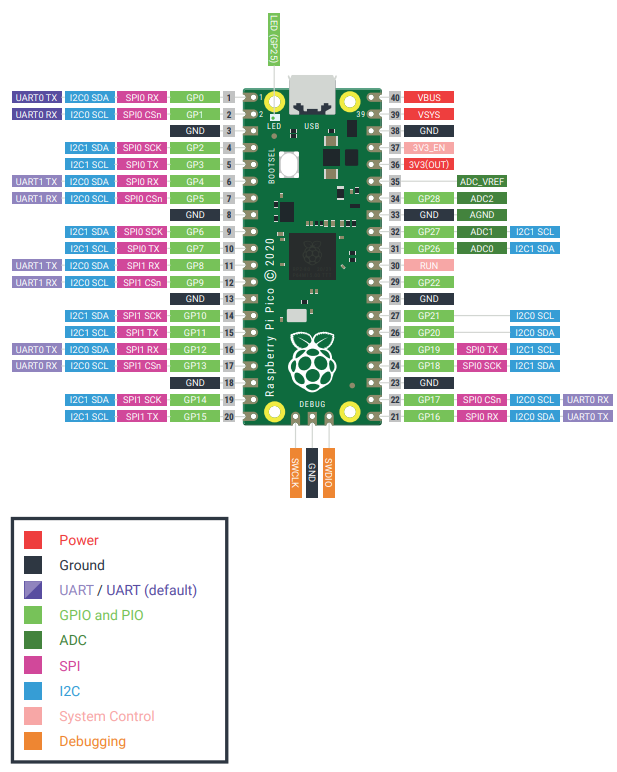
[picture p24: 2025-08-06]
SpecSheets/PicoPinsAll.png

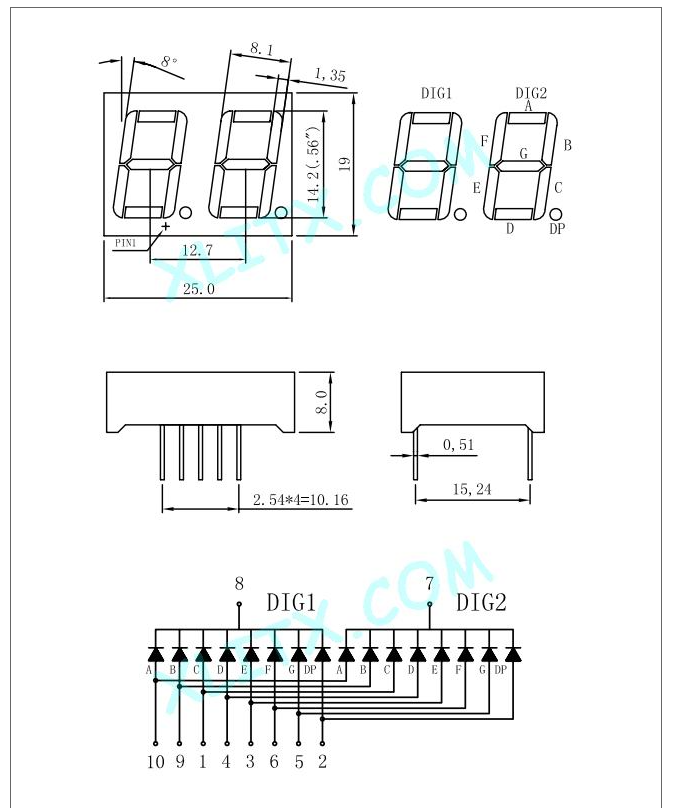
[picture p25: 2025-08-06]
SpecSheets/5621AH_schem.png

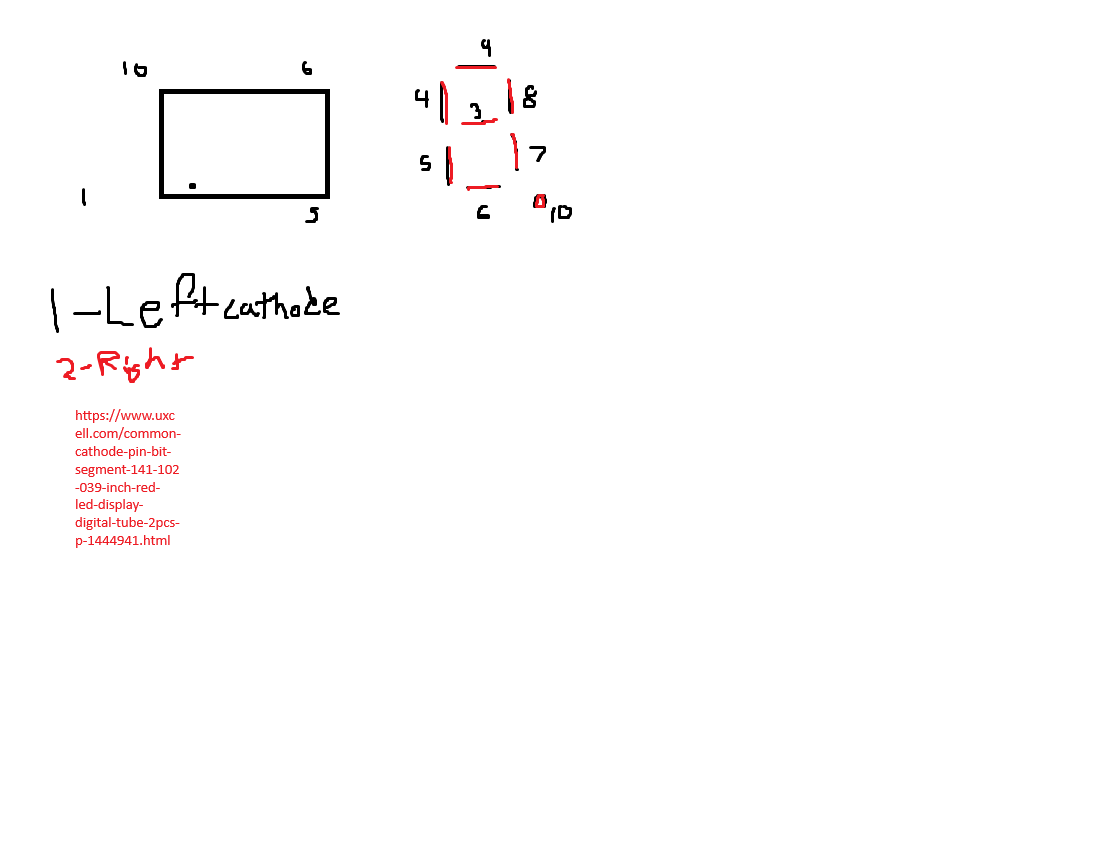
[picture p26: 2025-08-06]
SpecSheets/8021AH.png

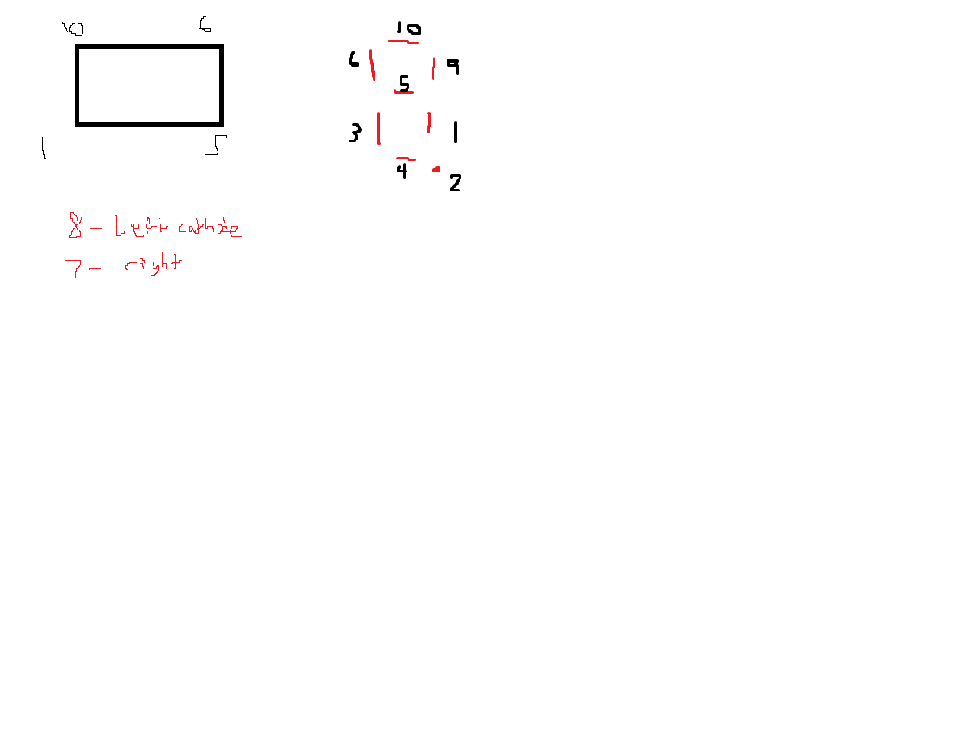
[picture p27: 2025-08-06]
SpecSheets/5621AH.png

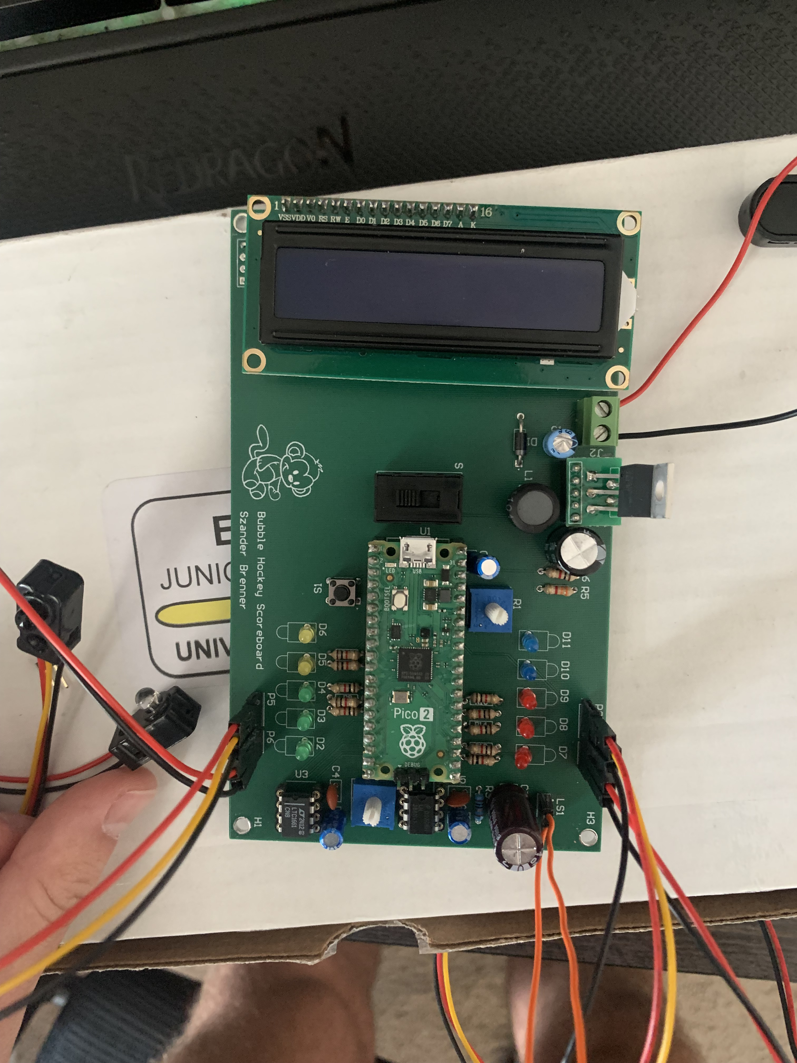
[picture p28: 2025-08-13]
Pictures/BubbleHockeyV1.jpg

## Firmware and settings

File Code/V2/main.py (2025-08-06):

from machine import UART, Pin
import time
import constants
import hardware
import game_logic
from neopixel import Neopixel



def main():
    #First initialize everything
    uart, spi, cs, adc, game_leds, colon_leds, beam_a, beam_b, start, select, busy_pin = hardware.init_hardware()
    hardware.init_scoreboard(cs, spi)
    game_logic.turnOffLEDs(cs, spi, colon_leds)
    # Init game state
    game = game_logic.GameState()
    
    #init pixels
    pixels = Neopixel(constants.NUM_PIXELS, constants.STATE_MACHINE, constants.PIXEL_PIN, constants.COLOR_PATTERN)
    
    #turn on lights
    pixels.fill((255, 255, 255))
    pixels.show()
    
    #turn on first indicator
    game_leds[0].value(1)
    for i in range(6):
        game_leds[i+1].value(0)
    colon_leds[0].value(0)
    colon_leds[1].value(0)
    
    
    
    time.sleep(1.5)
    volume = (adc.read_u16() * 31) // 65535
    hardware.uart_write(uart, constants.SET_VOLUME, 0x00, volume)
    game.current_volume = volume
    hardware.uart_write(uart, constants.PLAY_SONG, 0, 1)
    while(busy_pin.value()):
        #get flags
        flags = {
        'f_start' : hardware.f_start,
        'f_select' : hardware.f_select,
        'f_goalA' : hardware.f_goalA,
        'f_goalB' : hardware.f_goalB
        }
        if(flags['f_start']):
            break
    time.sleep(0.1)
    hardware.uart_write(uart, constants.SET_FOLDER, constants.SELECT_SOUNDS, 0x01)
    
    while True:
        #get flags
        flags = {
        'f_start' : hardware.f_start,
        'f_select' : hardware.f_select,
        'f_goalA' : hardware.f_goalA,
        'f_goalB' : hardware.f_goalB
        }
        
        if game.state == 'SELECT':
            game_logic.handle_select(game, cs, spi, adc, uart, flags, game_leds, colon_leds, start, select, pixels, busy_pin)
        elif game.state == 'GAME_RUNNING':
            game_logic.handle_game_running(game, cs, spi, uart, flags, adc, colon_leds, pixels, busy_pin)
        elif game.state == 'GAME_END':
            game_logic.handle_game_end(game, cs, spi, uart, colon_leds, flags, pixels, busy_pin)
                    
        hardware.clear_flags()      # clear flags on each loop
        
        time.sleep_ms(10)  # loop timing
        
        
main()

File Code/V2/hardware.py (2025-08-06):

from machine import Pin, SPI, I2C, ADC, Timer, UART
import time
import constants

f_start = False
f_select = False
f_goalA = False
f_goalB = False

#These are used to debounce the button and goal sensors
debounce_timer = Timer()


def spi_write(cs, spi, reg, data):
    cs.value(0)
    spi.write(bytearray([reg, data]))
    cs.value(1)
    
def uart_write(uart, cmd, param1=0, param2=1):
    msg = bytearray([
        0x7E, 0xFF, 0x06, cmd, 0x00,
        param1, param2,
        0x00, 0x00, 0xEF
    ])
    checksum = 0 - sum(msg[1:7]) & 0xFFFF
    msg[7] = (checksum >> 8) & 0xFF
    msg[8] = checksum & 0xFF
    uart.write(msg)
    

def init_UART():
    uart = UART(0, baudrate=9600, tx=Pin(constants.UART_TX), rx=Pin(constants.UART_RX))
    busy_pin = Pin(constants.BUSY_PIN, Pin.IN, Pin.PULL_UP)
    return uart, busy_pin
    
def init_SPI():
    sck= Pin(constants.SCLK_PIN)
    mosi = Pin(constants.MOSI_PIN)
    miso = Pin(constants.MISO_PIN)
    spi = SPI(1, baudrate = 400000, polarity = 0, phase = 0, firstbit=SPI.MSB, sck=sck, mosi=mosi, miso=miso)
    cs = Pin(constants.CS_PIN,mode = Pin.OUT, value = 1)
    return spi, cs
    
def init_ADC():
    adc = ADC(Pin(constants.ADC_PIN))
    return adc
    
def init_GameLEDs():
    gamemode_leds = [Pin(led, Pin.OUT) for led in constants.LED_GAMEMODE]
    return gamemode_leds
    
def init_TimeLEDs():
    colon_leds = [Pin(led, Pin.OUT) for led in constants.LED_COLON]
    return colon_leds
    
def init_BTNs():
    start  = Pin(constants.START_BTN, Pin.IN, Pin.PULL_UP)
    select = Pin(constants.SELECT_BTN, Pin.IN, Pin.PULL_UP)
    
    start.irq(trigger=Pin.IRQ_FALLING, handler=start_rst_handler)
    select.irq(trigger=Pin.IRQ_FALLING, handler=select_handler)
    return start, select
    
def init_beams():
    beam_a = Pin(constants.BEAM_A, Pin.IN, Pin.PULL_UP)   # Goal detection
    beam_b = Pin(constants.BEAM_B, Pin.IN, Pin.PULL_UP)
    
    beam_a.irq(trigger=Pin.IRQ_FALLING, handler=beam_a_handler)
    beam_b.irq(trigger=Pin.IRQ_FALLING, handler=beam_b_handler)
    return beam_a, beam_b
    

#collect all the objects i need in main and return in 1 package
def init_hardware():
    uart, busy_pin = init_UART()
    spi, cs = init_SPI()
    adc = init_ADC()
    game_leds = init_GameLEDs()
    colon_leds = init_TimeLEDs()
    beam_a, beam_b = init_beams()
    start, select = init_BTNs()
    
    return uart, spi, cs, adc, game_leds, colon_leds, beam_a, beam_b, start, select, busy_pin

def init_scoreboard(cs, spi):
    # Initialize MAX7219
    spi_write(cs, spi, constants.DISPLAY_TEST, 0x00)  # Display test off
    spi_write(cs, spi, constants.SHUTDOWN, 0x01)  # Shutdown register: normal operation
    spi_write(cs, spi, constants.DECODE_MODE, 0xFF)  # Decode mode: BCD for all digits
    spi_write(cs, spi, constants.INTENSITY, 0x0F)  # Intensity: max
    spi_write(cs, spi, constants.SCAN_LIMIT, 0x07)  # display all digits
    
    
#helpful things for hardware
def turnLEDsOff(cs, spi):
    spi_write(cs, spi, constants.SHUTDOWN, 0x0)
    
def turnLEDsOn(cs, spi):
    spi_write(cs, spi, constants.SHUTDOWN, 0x1)
    
    
    
#ISR Handlers
    #START BUTTON
def start_rst_handler(pin):
    debounce_timer.init(mode=Timer.ONE_SHOT, period=30, callback=lambda t: start_debounced(pin))
    
def start_debounced(pin):
    debounce_timer.deinit()
    if not pin.value():  # check that it's still pressed
        global f_start
        f_start = True
    
    #SELECT BUTTON
def select_handler(pin):
    debounce_timer.init(mode=Timer.ONE_SHOT, period=30, callback=lambda t: select_debounced(pin))
    
def select_debounced(pin):
    debounce_timer.deinit()
    if not pin.value():  # check that it's still pressed
        global f_select
        f_select = True
        
def beam_a_handler(pin):
    debounce_timer.init(mode=Timer.ONE_SHOT, period=10, callback=lambda t: beam_a_debounced(pin))

def beam_a_debounced(pin):
    debounce_timer.deinit()
    if not pin.value():
        global f_goalA
        f_goalA = True

def beam_b_handler(pin):
    debounce_timer.init(mode=Timer.ONE_SHOT, period=10, callback=lambda t: beam_b_debounced(pin))

def beam_b_debounced(pin):
    debounce_timer.deinit()
    if not pin.value():
        global f_goalB
        f_goalB = True
    
def clear_flags():
    global f_start, f_select, f_goalA, f_goalB
    f_start = False
    f_select = False
    f_goalA = False
    f_goalB = False

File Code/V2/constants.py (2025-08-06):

#UART Pins
UART_RX = 13
UART_TX = 12
BUSY_PIN = 7

#LEDS BETWEEN TIME
LED_COLON = [14, 15]


#LEDs for indicating game mode
LED_GAMEMODE = [16, 17, 18, 19, 20, 21, 22]


#Button Pins
START_BTN  = 0
SELECT_BTN = 1

#ADC Pin for volume
ADC_PIN = 28

#SPI Pins for MAX7219
MOSI_PIN = 11
MISO_PIN = 8
SCLK_PIN = 10
CS_PIN   = 9

#Beam Break Sensors
BEAM_A = 2
BEAM_B = 3

#MAX7219 Registers
NO_OP = 0x00
DIG0 = 0x01
DIG1 = 0x02
DIG2 = 0x03
DIG3 = 0x04
DIG4 = 0x05
DIG5 = 0x06
DIG6 = 0x07
DIG7 = 0x08
DECODE_MODE = 0x09
INTENSITY = 0x0A
SCAN_LIMIT = 0x0B
SHUTDOWN = 0x0C
DISPLAY_TEST = 0x0F

#DFPlayer Constants
ENTER_STANDBY = 0x0A
NORMAL_OPERATION = 0x0B
PLAY_SONG = 0x03
SET_FOLDER = 0x0F
SET_VOLUME = 0x06
PAUSE = 0x0E
RESET = 0x0C

#Songs number
SELECT_SOUNDS =0x01
GAME_TO_3 = 0x01
GAME_TO_5 = 0x02
GAME_TO_7 = 0x03
TIME_3    = 0x04
TIME_5    = 0x05
TIME_7    = 0x06
FREE_PLAY = 0x07

GAME_SOUNDS = 0x02
HORN        = 0x01
END_GOAL    = 0x02

END_SOUNDS = 0x03
FINAL_TIME = 0x01
RED_WIN = 0x02
BLACK_WIN = 0x03
TIE = 0x04

#Pixels stuff
NUM_PIXELS = 30
STATE_MACHINE = 0
PIXEL_PIN = 6
COLOR_PATTERN = "GRB"
